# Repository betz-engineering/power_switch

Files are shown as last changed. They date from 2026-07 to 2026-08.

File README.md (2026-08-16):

# power_switch
This electronic power switch was originally developed for a robotic buoy to disconnect the battery from the electronics and the motors.

The goal was to replace a large mechanical rotary switch, which wasn't fully waterproof, with a small tactile button behind a silicone membrane for 100 % leak-tightness.
The tactile button is only giving the ON/OFF command and the actual switching is done by a pair of beefy MOSFETs on the PCB.

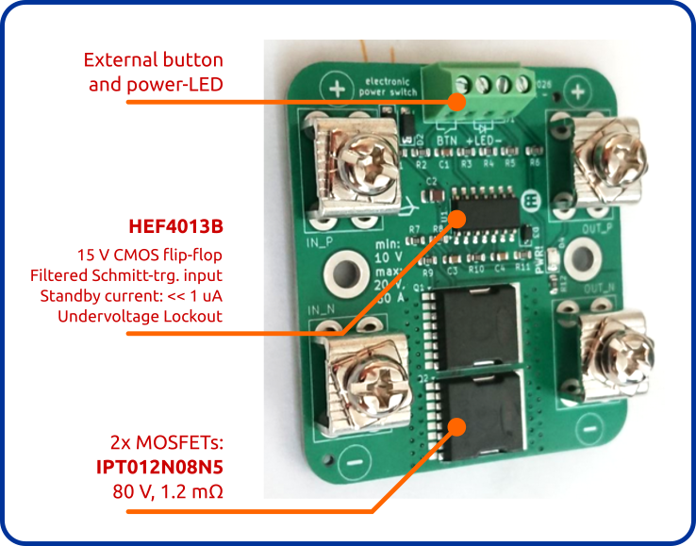
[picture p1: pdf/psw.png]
Overview of the power_switch


  * [Schematic](pdf/power_switch.pdf)
  * [Dimensions](pdf/power_switch_outline.pdf)

# License
Copyright 2026 Betz Engineering.

This source describes Open Hardware and is licensed under the CERN Open Hardware Licence Version 2 - Weakly Reciprocal (CERN-OHL-W-2.0).

You may redistribute and modify this source and make products using it under the terms of the CERN-OHL-W-2.0 (spdx.org).

This source is distributed WITHOUT ANY EXPRESS OR IMPLIED WARRANTY, INCLUDING OF MERCHANTABILITY, SATISFACTORY QUALITY AND FITNESS FOR A PARTICULAR PURPOSE. See the CERN-OHL-W-2.0 for conditions of licence.

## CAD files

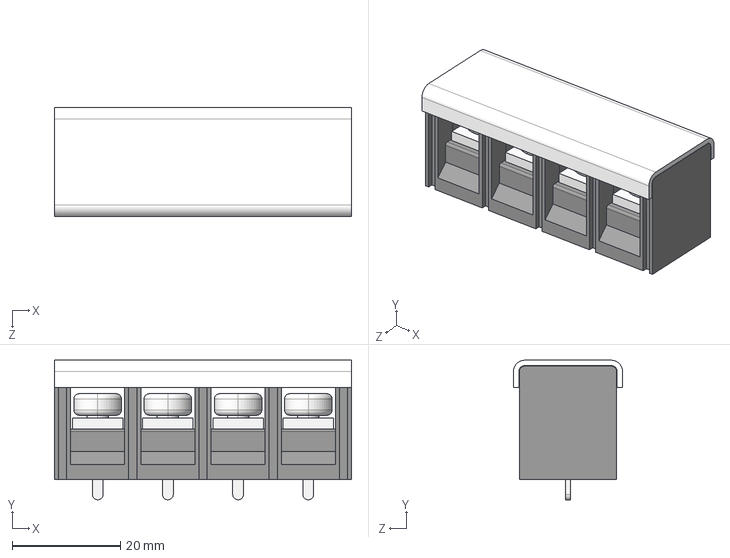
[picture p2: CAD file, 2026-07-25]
3d/KF78C-13_0-4P.step
55.0 x 25.9 x 20.2 mm

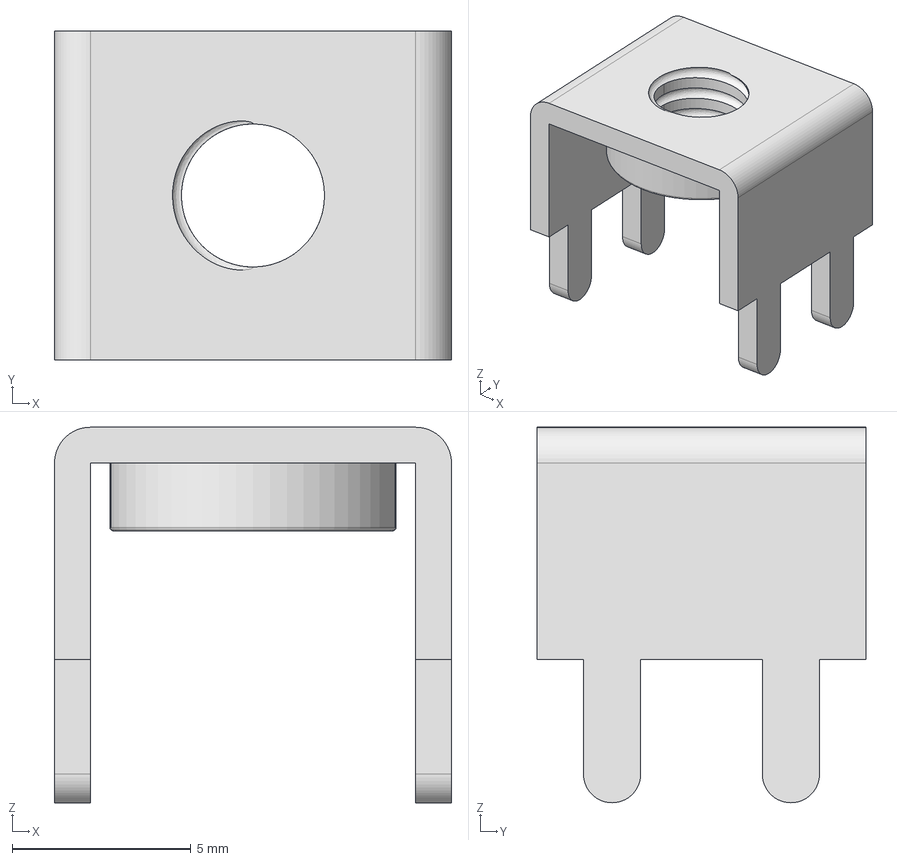
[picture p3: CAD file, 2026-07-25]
3d/T44007.step
11.1 x 9.20 x 10.5 mm

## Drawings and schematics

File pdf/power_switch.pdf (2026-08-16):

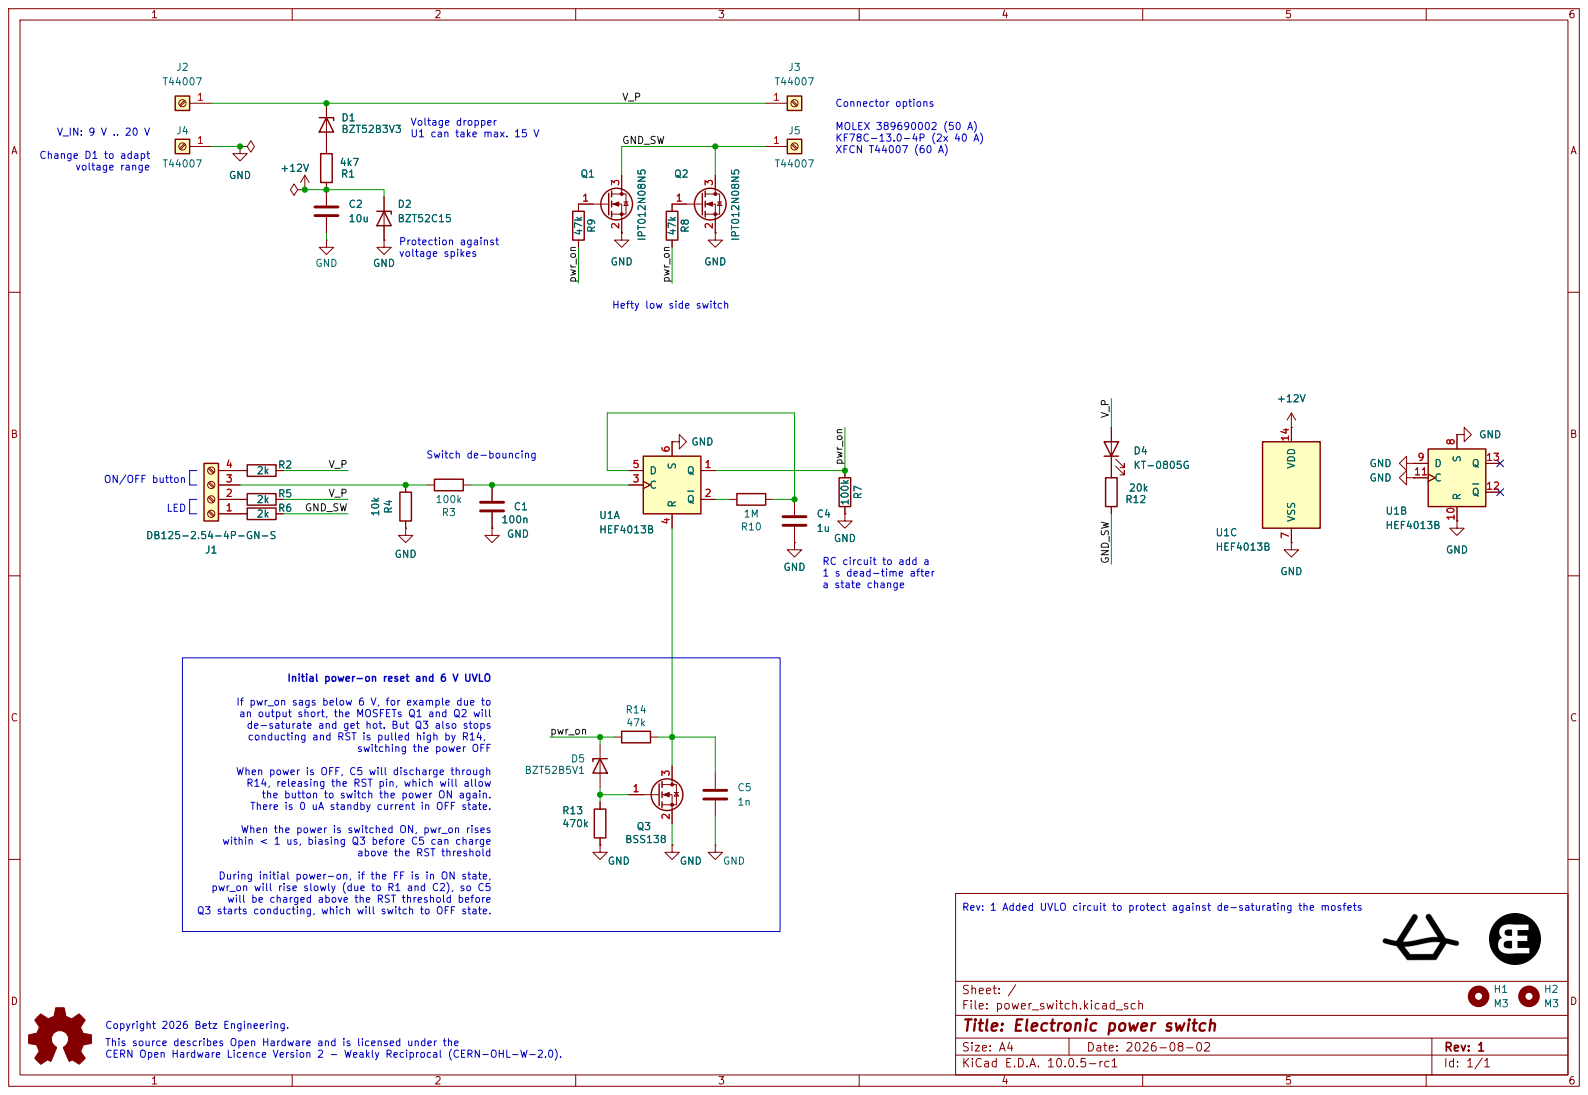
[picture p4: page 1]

Hefty low side switch

Rev: 1 Added UVLO circuit to protect against de-saturating the mosfets R7 100k GND

Initial power-on reset and 6 V UVLO

If pwr_on sags below 6 V, for example due to
an output short, the MOSFETs Q1 and Q2 will de-saturate and get hot. But Q3 also stops

conducting and RST is pulled high by R14,
switching the power OFF When power is OFF, C5 will discharge through

R14, releasing the RST pin, which will allow

Sheet: /
File: power_switch.kicad_sch
Title: Electronic power switch

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

Size: A4 | Rev: 1
KiCad E.D.A. 10.0.5-rc1 | Id: 1/1

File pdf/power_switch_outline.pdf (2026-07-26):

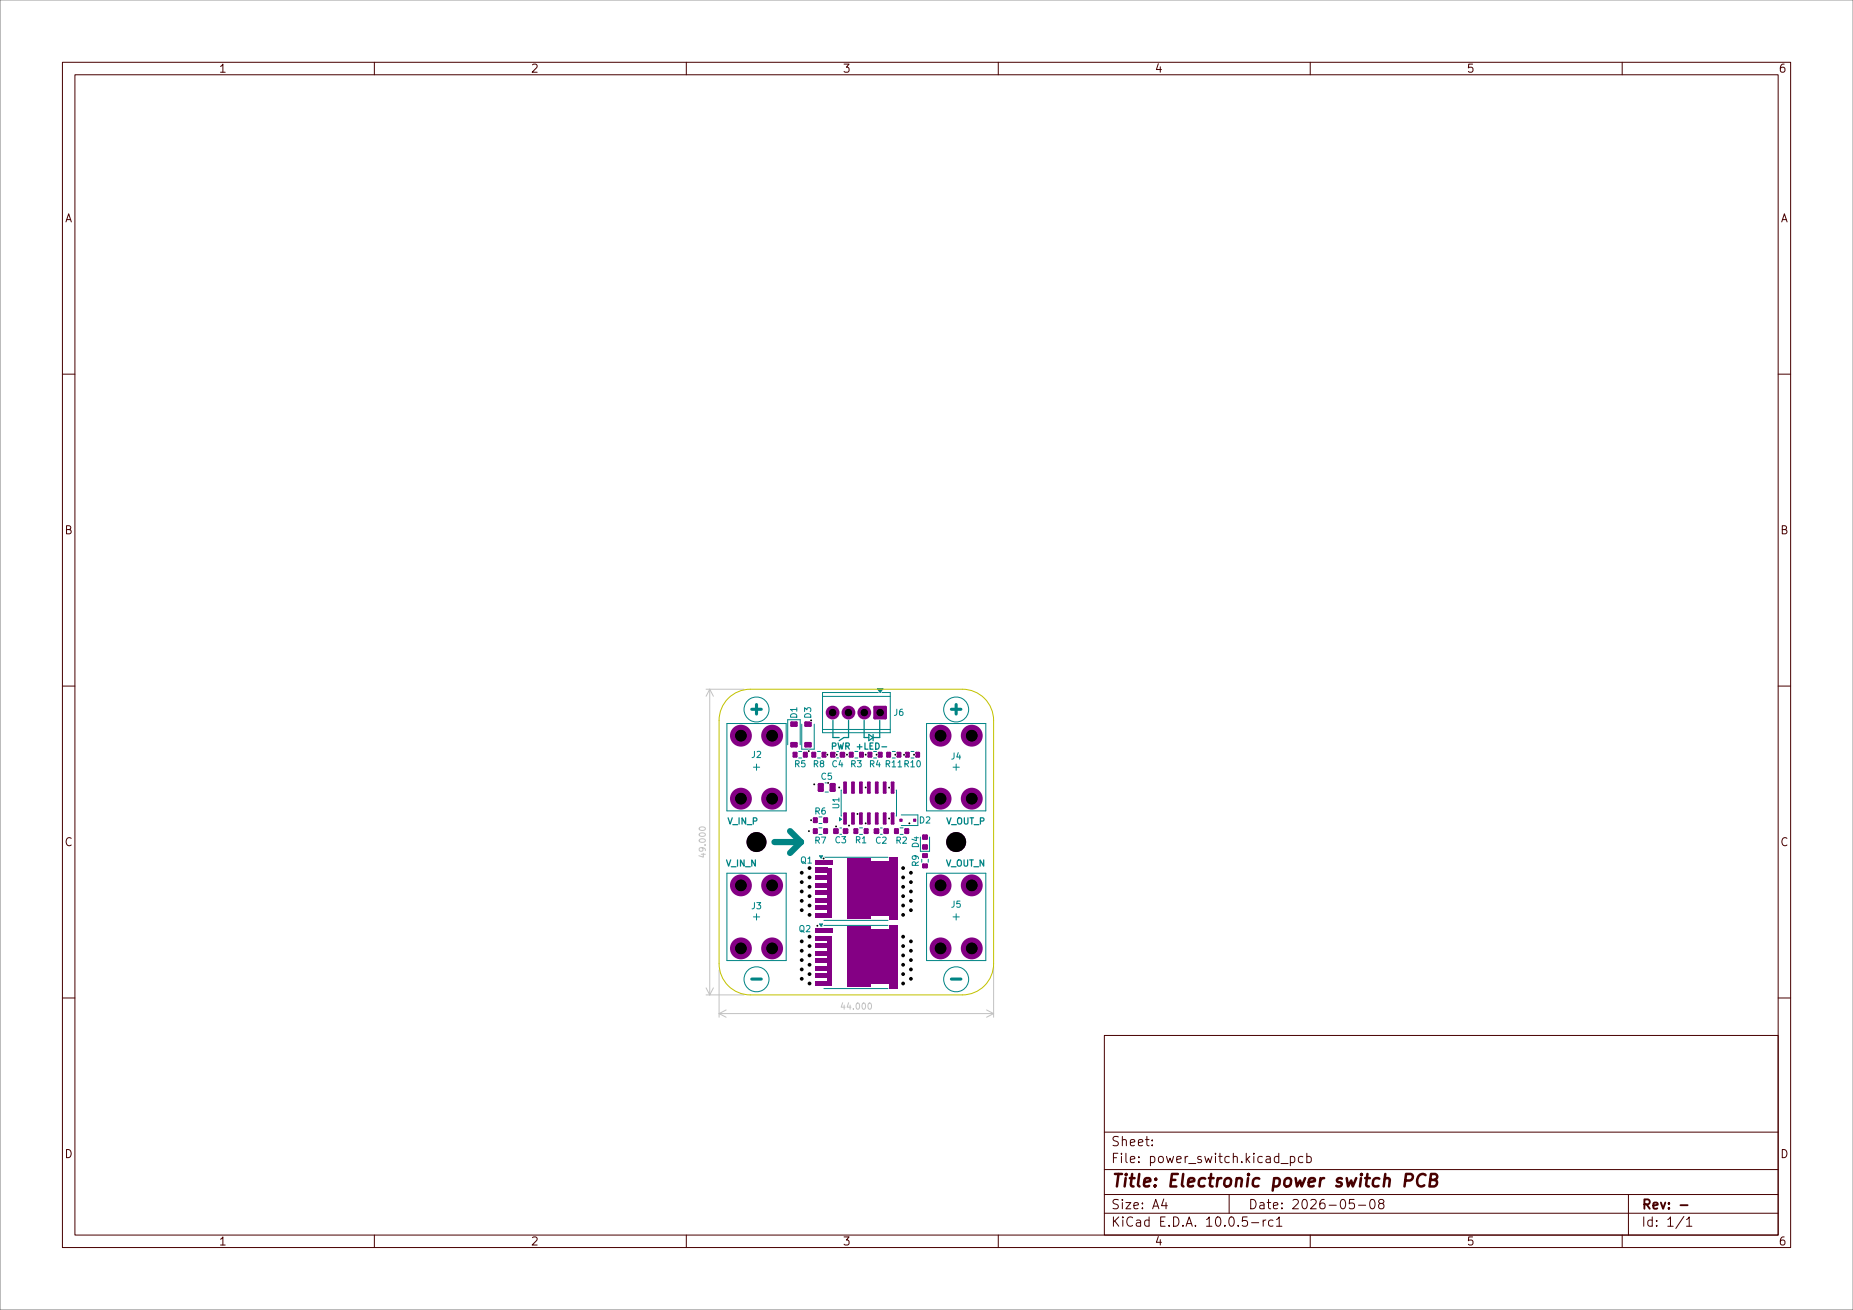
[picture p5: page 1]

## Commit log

2026-07-20 initial schematic
    [power_switch.kicad_pcb, power_switch.kicad_sch]
2026-07-21 mosfet package
    [power_switch.kicad_sch]
2026-07-25 component choice finished. PCB placement started
    [KF78C-13_0-4P.step, power_switch.kicad_pcb, power_switch.kicad_sch]
2026-07-25 add screw terminals, route connections
    [T44007.step, power_switch.kicad_pcb, power_switch.kicad_sch]
2026-07-25 put back vertical connector, optimize planes
    [power_switch.kicad_pcb, power_switch.kicad_sch]
2026-07-25 add LED and shunt zener
    [power_switch.kicad_pcb, power_switch.kicad_sch]
2026-07-26 switch to screw terminals
    [power_switch.kicad_pcb, power_switch.kicad_sch]
2026-07-26 add .pdf of outline of PCB
    [power_switch.kicad_pcb]
2026-07-26 fix some DRC errors
    [power_switch.kicad_pcb, power_switch.kicad_sch]
2026-07-26 fix silkscreen
    [power_switch.kicad_pcb]
2026-07-26 add 100k pulldown to mosfet gate
    [power_switch.kicad_pcb, power_switch.kicad_sch]
2026-08-01 Optimized fills. Final version. Ordering.
    [power_switch.kicad_pcb]
2026-08-01 re-reoute and anticipate the inner layers to have 2 OZ of copper
    [power_switch.kicad_pcb]
2026-08-02 nicer silk-screen
    [power_switch.kicad_pcb, power_switch.kicad_sch]
2026-08-02 switch to 0805 LED (basic part)
    [power_switch.kicad_pcb, power_switch.kicad_sch]
2026-08-13 add idea for UVLO with a single additional BSS138
    [power_switch.kicad_sch]
2026-08-13 UVLO: fine tune component values, add ltspice simulation
    [power_switch.kicad_sch]
2026-08-13 add UVLO circuit to layout
    [power_switch.kicad_pcb]
2026-08-14 finalized rev 1 for production
    [power_switch.kicad_pcb, power_switch.kicad_sch]
2026-08-14 update revision number on PCB to rev: 1
    [power_switch.kicad_pcb]
2026-08-14 typo in schematic
    [power_switch.kicad_sch]
2026-08-16 update and add LICENSE note
    [power_switch.kicad_pcb, power_switch.kicad_sch]
